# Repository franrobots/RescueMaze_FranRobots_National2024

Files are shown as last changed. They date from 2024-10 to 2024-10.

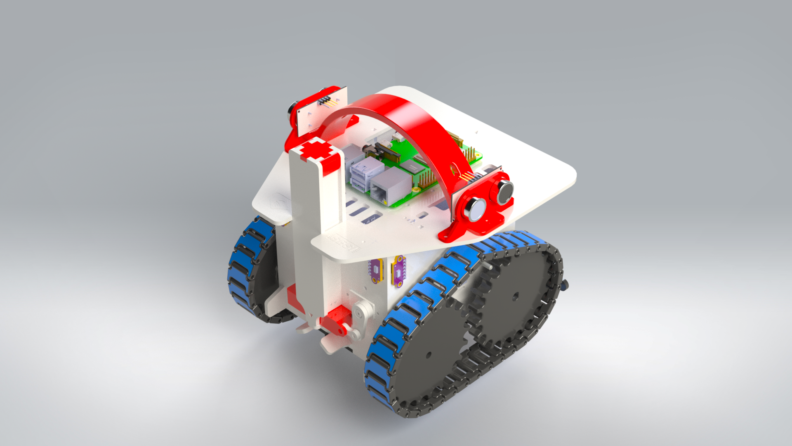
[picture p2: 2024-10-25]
Mechanics/MAZE ROBOT 2024/Extras/Render/Renders Robô/Projeto sem título.png

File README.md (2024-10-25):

# RescueMaze_FranRobots_National2024
🌎 Ready to face the exciting challenges of the Rescue Maze competition at RoboCup Junior! <br>

This repository is dedicated to organizing and centralizing documents, pictures, and files related to the 2024 Rescue Maze competition from RoboCup Junior, in [Goiania, BR](https://pt.wikipedia.org/wiki/Goi%C3%A2nia).

**Team Members:**
* [Arthur Mendes](https://www.instagram.com/arthurmlopezzz/) <br>
* [João Ribeiro](https://www.instagram.com/jaotavin/) <br>
* [Fernanda Lima](https://www.instagram.com/ferdilima_/) <br>
* [Guilherme Canteiro](https://www.instagram.com/guilhermebcanteiro/) <br>

<p align="center">
TeamMembers
<p align="center">  <strong> Team Members </strong> </p>

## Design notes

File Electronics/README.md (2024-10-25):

# Electronics ⚡

📜 This folder is intended for the [team's](https://www.instagram.com/fran_robots) robot electronic development. <br>

Here you can find the schematics, PCB layouts, and physical circuits of the project! [EasyEDA](https://easyeda.com/) is used to make the schematics and PCB layouts. <br> 
<br>
**Authors:**
* [Arthur Mendes](https://www.instagram.com/arthurmlopezzz/)
* [Guilherme Canteiro](https://www.instagram.com/guilhermebcanteiro/) <br>
<br>

> 💡 The electronics involve developing a robot that perceives its environment, makes decisions based on that perception, and executes actions necessary to **effectively** complete the competition tasks. <br>
> <br>
📟 Each electrical component plays a **specific** role in this process, working together to achieve **success** in the competition.

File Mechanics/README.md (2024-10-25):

# Mechanics
📜 This folder is designed to organize all robot mechanics-related content for the [team](https://github.com/franrobots), competing in the Rescue Maze category at RoboCup Junior. <br>

It contains essential documents, photos, and CAD ([SolidWorks](https://www.solidworks.com/)) project files. <br>
<br>

**Authors:**
* [Arthur Mendes](https://www.instagram.com/arthurmlopezzz/) <br>
* [Fernanda Lima](https://www.instagram.com/ferdilima_/) <br>
* [Guilherme Canteiro](https://www.instagram.com/guilhermebcanteiro/) <br>
<br>

> ⚙️ Mechanical development involves creating a **robust** structure, an **efficient** locomotion system, a **reliable** firing mechanism, and integrating precise electronic sensors to build an **effective** robot for competition.
<br>
<p align="center">
3D Assembly of the robot
<p align="center">  <strong> 3D Assembly of the Robot </strong> </p>

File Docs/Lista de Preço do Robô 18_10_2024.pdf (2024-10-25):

10/18/2024 | 1

### Lista de Preço do Robô - Fran Robots RCJ Rescue Maze

Item | Preço | Unidades por Pacote | Pacotes | Unidades Usadas | Total | Referência
LDR (Resistor Dependente de Luz) 5mm | R$14.32 | 100 unidades | 1 | 3 | R$14.32 | Link (https://pt.aliexpress.com/item/1005003401017855.html)
Resistor 1/4W 10K Ohm | R$8.22 | 100 unidades | 1 | 20 | R$8.22 | Link (https://pt.aliexpress.com/item/1005002369580841.html)
Resistor 1/4W 110 Ohm | R$8.22 | 100 unidades | 1 | 1 | R$8.22 | Link (https://pt.aliexpress.com/item/1005002369580841.html)
Resistor 1/4W 10K Ohm | R$8.22 | 100 unidades | 1 | 20 | R$8.22 | Link (https://pt.aliexpress.com/item/1005002369580841.html)
Resistor 1/4W 110 Ohm | R$8.22 | 100 unidades | 1 | 1 | R$8.22 | Link (https://pt.aliexpress.com/item/1005002369580841.html)
Capacitor 1uF 50V | R$14.91 | 50 unidades | 1 | 1 | R$14.91 | Link (https://pt.aliexpress.com/item/1005005248329912.html)
LED Branco Alto-brilho de 5mm | R$5.79 | 100 unidades | 1 | 3 | R$5.79 | Link (https://pt.aliexpress.com/item/32918676633.html)
CTK C9L3 Sensor Infravermelho Refletivo | R$7.00 | 1 unidade | 3 | 3 | R$21.00 | Link (https://www.acheicomponentes.com.br/chaves/chave-otica-infravermelha-refletiva-compacta-ctk-c9l3-ctk)
Motor DC de 50RPM com caixa de redução - MJ TEK8 12V | R$138.00 | 1 unidade | 2 | 2 | R$276.00 | Link (https://produto.mercadolivre.com.br/MLB-925938177)
Driver de Motor Dupla Ponte H L298N HS | R$19.90 | 1 unidade | 1 | 1 | R$19.90 | Link (https://www.eletrogate.com/ponte-h-dupla-l298n?gad_source=1)
Display de Bateria MH-DL18S | R$18.90 | 1 unidade | 1 | 1 | R$18.90 | Link (https://produto.mercadolivre.com.br/MLB-1159926996)
Bateria Lipo Leão 11.1v 3s 2.2ah 30c/60c | R$299.00 | 1 unidade | 1 | 1 | R$299.00 | Link (https://produto.mercadolivre.com.br/MLB-1697260577-bateria-lipo-111v-3s-2200mah-30c60c-xt60-_JM)
Conector Fêmea de Bateria XT60 | R$6.56 | 1 unidade | 1 | 1 | R$6.56 | Link (https://pt.aliexpress.com/item/1005003677606547.html)
Regulador Step Down DC-DC Mini 360 3A | R$7.22 | 1 unidade | 2 | 2 | R$14.44 | Link (https://es.aliexpress.com/item/1005006243045808.html)
Regulador Step Up DC-DC MT3608 2A | R$11.99 | 1 unidade | 1 | 1 | R$11.99 | Link (https://produto.mercadolivre.com.br/MLB-1840280546-modulo-regulador-dc-step-up-mt3608-conversor-pic-_JM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)
Placa Ilhada de Fenolite 10x10cm | R$12.90 | 1 unidade | 1 | 1 | R$12.90 | Link (https://www.robocore.net/placa-circuito/pcb-ilhada-10x10cm)
ESP32-WROOM-32 30 Pinos | R$4.99 | 1 unidade | 1 | 1 | R$4.99 | Link (https://es.aliexpress.com/item/1005006246777139.html)
Multiplexador I2C 8 Canais TCA9548A | R$8.53 | 1 unidade | 1 | 1 | R$8.53 | Link (https://es.aliexpress.com/item/1005006770076868.html)
GY-BNO055 9-Axis Abs. Orientation | R$44.20 | 1 unidade | 1 | 1 | R$44.20 | Link (https://es.aliexpress.com/item/1005006878899969.html)
VL53L0X Time-Of-Flight Laser Ranging Sensor | R$4.99 | 8 unidades | 1 | 8 | R$4.99 | Link (https://es.aliexpress.com/item/1005006719586781.html)
Módulo Sensor de Distância Ultrassônico HC-SR04 | R$11.90 | 1 unidade | 2 | 2 | R$23.80 | Link (https://www.eletrogate.com/modulo-sensor-de-distancia-ultrassonico-hc-sr04?gad_source=1)
Mini Rocker Switch KCD11-101 | R$1.60 | 10 unidades | 1 | 3 | R$1.60 | Link (https://www.eletrogate.com/mini-chave-gangorra-2-terminais?gad_source=1)
SG90 9G Micro Servo 180º | R$16.73 | 1 unidade | 1 | 1 | R$16.73 | Link (https://pt.aliexpress.com/item/1005006379480535.html)
Fita de LED RGB Individualmente Endereçável 5V | R$5.98 | 1 unidade | 1 | 1 | R$5.98 | Link (https://pt.aliexpress.com/item/4000636732242.html)
Raspberry PI 4 Modelo B 8GB | R$286.81 | 1 unidade | 1 | 1 | R$286.81 | Link (https://pt.aliexpress.com/item/1005005761716573.html)
WebCam Generica FullHD | R$16.27 | 1 unidade | 2 | 2 | R$32.54 | Link (https://pt.aliexpress.com/item/1005005831256349.html)
Cabo USB 1m | R$70.16 | 1 unidade | 1 | 1 | R$70.16 | Link (https://pt.aliexpress.com/item/1005005201739767.html)
Cabo USB A 2.0 1m | R$18.72 | 1 unidade | 2 | 2 | R$37.44 | Link (https://pt.aliexpress.com/item/1005006854476947.html)
Borne 2-Vias 5.08mm WJ128 | R$2.51 | 5 unidades | 2 | 9 | R$5.02 | Link (https://pt.aliexpress.com/item/1005006277429830.html)
Barra Pinada Macho 2.54mm 1x40 | R$19.74 | 10 unidades | 1 | 2 | R$19.74 | Link (https://pt.aliexpress.com/item/1005002577212594.html)
Barra Pinada Fêmea 2.54mm 1x40 | R$19.74 | 10 unidades | 1 | 3 | R$19.74 | Link (https://pt.aliexpress.com/item/1005002577212594.html)

10/18/2024
2
Jumper Fêmea 20cm | R$4.47 | 10 unidades | 1 | 2 | R$4.47 | Link (https://www.proesi.com.br/jumper-femea-x-femea-kit-com-10-unidades-12cm)
Cabo Flat Multi-colorido AWG26 | R$9.64 | 1 metro | 3 | 3 | R$28.92 | Link (https://www.eletrodex.net/cabos-e-fios/flat-cable/colorido/cabo-flat-colorido-awg26)
Alça Impressa em 3D | R$29.26 | 1 unidade | 1 | 1 | R$29.26
Caixa Tripla de LDR Impressa em 3D | R$16.58 | 1 unidade | 1 | 1 | R$16.58
Kit de Resgate Impresso em 3D | R$17.92 | 12 unidades | 1 | 12 | R$17.92
Suporte do Switch do Principal Impresso em 3D | R$16.04 | 1 unidade | 1 | 1 | R$16.04
Roda Motora Impressa em 3D | R$38.55 | 1 unidade | 2 | 2 | R$77.10
Roda Boba Impressa em 3D | R$37.71 | 1 unidade | 2 | 2 | R$75.42
Dentes da Esteira Impressos em 3D | R$53.21 | 20 unidades | 4 | 72 | R$212.84
Junção da Esteira Impressa em 3D | R$21.22 | 20 unidades | 4 | 72 | R$84.88
Pistão "Tapete" Impresso em 3D | R$17.39 | 1 unidade | 1 | 1 | R$17.39
Para-choque Tátil Meio Impresso em 3D | R$16.67 | 1 unidade | 1 | 1 | R$16.67
Para-choque Tátil Lateral Impresso em 3D | R$17.50 | 2 unidade | 1 | 2 | R$17.50
Tampa Disparador Impressa em 3D | R$16.40 | 1 unidade | 1 | 1 | R$16.40
Placa de Acrílico Transparente 3mm 60x40cm | R$67.00 | 1 unidade | 1 | 1 | R$67.00 | Link (https://produto.mercadolivre.com.br/MLB-3922190696-chapa-acrilico-cristal-60x40-cm-x-3-mm-artesanato-laser-_JM)
Cola de silicone 85g | R$12.94 | 1 unidade | 1 | 1 | R$12.94 | Link (https://www.casadosparafusosfranca.com.br/cola-fixa-tudo-ms-profissional-amazonas-bisnaga-85g-amazonas)
Borracha De Silicone Azul Alta Flexibilidade para Moldes | R$35.90 | 515 gramas | 1 | 200g | R$35.90 | Link (https://www.redelease.com.br/catalog/product/view/id/8530/s/borracha-de-silicone-azul-alta-flexibilidade-para-moldes-com-catalisador-515-g/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)
Parafuso Fenda M2.5 16mm | R$0.57 | 1 unidade | 14 | 14 | R$7.98 | Link (https://www.casadoresistor.com.br/parafuso-m2,5x16-cabeca-cilindrica-fenda-p7099)
Porca M2.5 | R$0.11 | 1 unidade | 26 | 26 | R$2.86 | Link (https://www.casadoresistor.com.br/porca-sextavada-m2,5-p7156)
Arruela M2.5 | R$0.14 | 1 unidade | 4 | 4 | R$0.56 | Link (https://www.megalojista.com.br/fixadores/arruelas/arruela-lisa/arruela-lisa-m2-5-2-7-x-6-x-0-55-din-125a-inox-a2-unidade.html)
Parafuso Allen Inox M3 12mm | R$0.36 | 1 unidade | 30 | 30 | R$10.80 | Link (https://www.dallanese.com.br/8169/pf-allen-c-cabea-mm-ma-inox-304)
Parafuso Fenda de Cabeça Chata M3 30mm | R$0.30 | 1 unidade | 2 | 2 | R$0.60 | Link (https://www.parafusofacil.com.br/ProdutosDetalhes.php?Codigo=1099274)
Parafuso Fenda M3 20mm | R$0.21 | 1 unidade | 8 | 8 | R$1.68 | Link (https://www.parafusofacil.com.br/ProdutosDetalhes.php?Codigo=1099229)
Parafuso Fenda de Cabeça Chata M3- 6mm | R$0.13 | 1 unidade | 8 | 8 | R$1.04 | Link (https://www.parafusofacil.com.br/ProdutosDetalhes.php?Codigo=1099267)
Porca Inox M3 | R$0.12 | 1 unidades | 51 | 51 | R$6.12 | Link (https://www.parafusofacil.com.br/porcas/porca-sextavada/porca-sextavada-ma-3-0-50-chave-5-5-inox-304a2-classe-70-passivado)
Porca Nylon Baixa MA3 | R$0.31 | 1 unidade | 2 | 2 | R$0.62 | Link (https://www.parafusofacil.com.br/ProdutosDetalhes.php?Codigo=1245278)
Arruela M3 | R$3.20 | 10 unidades | 1 | 8 | R$3.20 | Link (https://loja.forsetisolucoes.com.br/arruela-lisa)
Parafuso Allen Inox de Rosca Completa M4 30mm | R$1.14 | 1 unidade | 2 | 2 | R$2.28 | Link (https://www.parafusofacil.com.br/ProdutosDetalhes.php?Codigo=1112392)
Porca Inox M4 | R$0.15 | 1 unidade | 6 | 6 | R$0.90 | Link (https://www.parafusofacil.com.br/porcas/porca-sextavada/porca-sextavada-ma-4-0-70-chave-7-inox-304a2-classe-70-passivado/)
Arruela M4 | R$2.40 | 10 unidades | 1 | 4 | R$2.40 | Link (https://loja.forsetisolucoes.com.br/arruela-lisa)

Total Geral
R$2,119.13

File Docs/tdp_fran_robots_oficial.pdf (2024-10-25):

# RoboCupJunior Brasil – Rescue Maze – TDP Fran Robots

1

° Arthur Mendes Lopes
SESI-SP
Franca, Brasil
arthur.mendes2801@gm
ail.com

2° Fernanda de Lima
Gonçalves
SESI-SP
Franca, Brasil
fernandalima99995788
@gmail.com

3

° Guilherme Baptista
Canteiro
SESI-SP
Franca, Brasil
guilhermebcanteiro@gm
ail.com

4° João Otávio Silva
Ribeiro
SESI-SP
Franca, Brasil
silvaribeirojoaootavio@
gmail.com

Resumo — Este artigo apresenta o desenvolvimento de nosso robô para a competição RoboCupJunior Rescue Maze, realizado ao longo de um ano e três meses. Para a navegação, tratamos o labirinto como uma grade de vértices e arestas (grafos), permitindo ao robô construir um mapa eficiente para localizar-se e encontrar rotas inteligentes. Optamos por priorizar tarefas no core (núcleo) 0 da ESP32, configurando-as com prioridade 1, o que resultou em um aumento significativo na velocidade de execução do programa. No hardware, além de um para-choque sensível equipado com botões que detectam paredes e obstáculos ao colidir, fazemos o uso de um sensor ultrassônico que valida a identificação de vítimas pela Raspberry Pi 4, garantindo que elas estejam em uma parede próxima. Isso previne os problemas anteriores com a detecção de vítimas falsas em paredes distantes. Também desenvolvemos um sistema de disparo com mecanismo biela-manivela para lançar kits de resgate em ambas as direções (direita e esquerda), utilizando apenas um servo motor. Essas inovações visam aumentar a eficiência e a precisão nas missões de resgate, reduzindo o tempo de resposta e aumentando a capacidade de adaptação do robô ao ambiente.
Palavras-chave — Labirinto, RoboCupJunior-Brasil, Robótica-Educacional, Machine-Learning, K-Means.
I. VISÃO GERAL
É a segunda vez que estamos participando dessa competição, mas, nos inspiramos muito nos conhecimentos que adquirimos anteriormente na competição RoboCupJunior Rescue Line. Nesse ano, aprimoramos o design do nosso robô, buscando maior simplicidade e eficiência. A estrutura modular, com peças transparentes e 3D, facilita a manutenção e o diagnóstico de problemas. As esteiras, antes com borracha de câmara de ar, agora com silicone, garantem maior aderência em diferentes terrenos do labirinto.
Para a navegação autônoma, desenvolvemos um sistema em C++ [01] que representa o labirinto como um grafo [02], permitindo a construção de mapas e a busca de rotas otimizadas e inteligentes. Sensores detectam paredes, caminhos e vítimas nas paredes, auxiliando na localização e na tomada de decisões. A visão computacional, implementada em Python [03] com OpenCV [04], utiliza os 7 Momentos de Hu [05] e o algoritmo K-Means [06] para identificar e classificar vítimas com alta precisão, mesmo em condições de iluminação variável. Essa combinação de técnicas permite ao robô reconhecer padrões visuais complexos e adaptar-se às diferentes situações encontradas durante a competição.
Os aprimoramentos realizados no robô desde o ano passado resultaram em um desempenho consideravelmente melhor. Sua maior estabilidade e precisão na identificação de vítimas demonstram um avanço significativo em direção ao objetivo de criar um sistema de resgate autônomo mais eficiente.

II. PLANEJAMENTO GERAL DO PROJETO
O principal objetivo da nossa equipe nesta competição é aprimorar de forma significativa as capacidades de reconhecimento de imagem do nosso robô, buscando um desempenho otimizado. Para isso, definimos metas específicas
que | incluem | melhorar | a | precisão | do | sistema | de
reconhecimento e reduzir o tempo necessário para a conclusão das tarefas.
Nossas atividades estão registradas no Diário de Engenharia (Figura 1), desenvolvido no Canva [07], o que nos permitiu documentar nossas ações diárias com eficiência e manter uma organização clara. O diário também funciona como um planejador de metas a curto e longo prazo, além de incluir detalhes importantes de tarefas específicas. Registrar essas informações torna a execução dessas atividades mais prática no futuro, já que todos os procedimentos e soluções anteriores estão devidamente registrados.
O uso do Canva, que reúne todos os componentes do robô, também foi essencial durante o processo de montagem, proporcionando acesso simplificado e prático a informações críticas, como datasheets dos sensores.

FIGURA 1
PÁGINAS DO DIÁRIO DE ENGENHARIA DA FRAN ROBOTS, CAPA GERAL, CAPA DA ÁREA, PÁGINA ALEATÓRIA, RESPECTIVAMENTE.

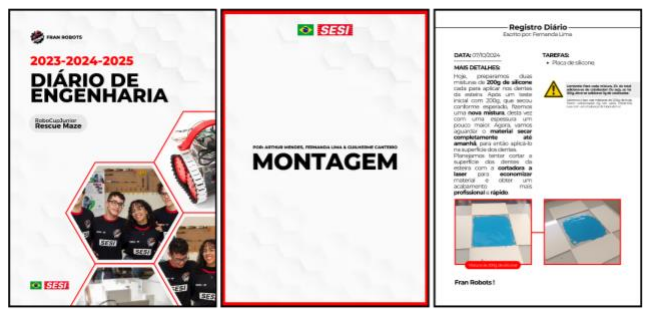
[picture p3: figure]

III. ESTRUTURA DO ROBÔ E ELETRÔNICA
Nosso robô foi projetado com uma arquitetura robusta e modular, permitindo adaptações rápidas e soluções eficazes durante a competição. O hardware principal é composto por uma série de componentes cuidadosamente selecionados e otimizados para garantir o máximo desempenho no labirinto.
A. Mecânica e Manufatura
1. Estrutura Principal
Projetado em CAD [08] (Figura 2a e 2b), o robô prioriza confiabilidade e estabilidade enquanto mantém um tamanho compacto, simplificando o desenvolvimento do software e da eletrônica. Ele possui fácil acesso por cima e por baixo, com poucos parafusos para manutenções rápidas. Porcas coladas com supercola em “junções T” (Figura 2c) evitam perdas e facilitam a montagem rápida. Os sensores e as câmeras são meticulosamente alinhados dentro das restrições físicas (tamanho e campo de visão), garantindo uma visão abrangente do labirinto.

FIGURA 2
(A) MODELO 3D DO ROBÔ; (B) ROBÔ REAL; (C) JUNÇÃO EM T.

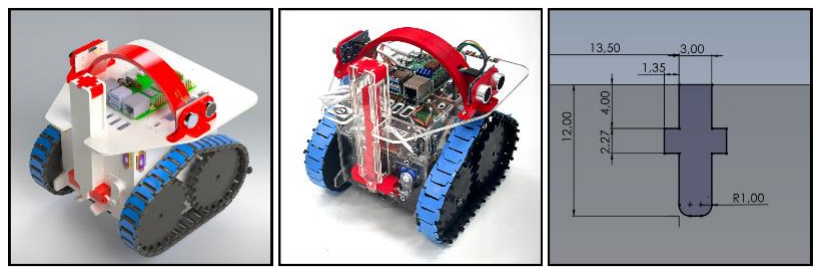
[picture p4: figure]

2. Rodas, Motores e Encoder As engrenagens, uma acionada por um motor e a outra livre (Figura 3a), movimentam as esteiras do robô. Um parafuso e uma porca são usados para fixação da “roda boba”. Os motores operam com tração nas rodas dianteiras, priorizando um melhor desempenho ao subir rampas, ao mesmo tempo que protegem o disparador de kits durante as descidas. Um encoder
[09] é colocado no lado direito com um ímã, dentro da roda livre (Figura 3b), Ele lê as rotações e as conta para validação dos ladrilhos e movimentos mais rápidos do robô

FIGURA 3
(A) RODA LIVRE (ESQUERDA) E RODA MOTORA (DIREITA); (B) RODA LIVRE E ÍMÃ DO ENCODER.

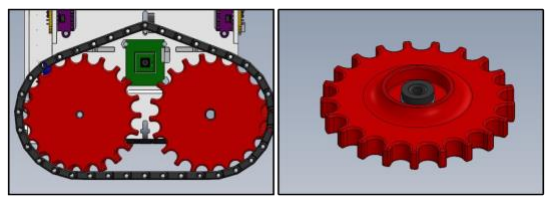
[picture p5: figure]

3. Esteiras Modulares
As esteiras do nosso robô foram baseadas em nossa estratégia anterior na Olímpiada Brasileira de Robótica [10]. Elas garantem maior estabilidade geral, especialmente ao subir escadas (Figura 4a), superar redutores de velocidade e navegar por detritos espalhados pela arena. A parte superior garante que as rodas não batam nas paredes do labirinto e as escalem, ajudando no alinhamento. Nossa esteira é modular. De maneira similar à elos de uma corrente, utilizar dentes impressos em filamento ABS e conectá-los por pinos (Figuras 4b, 4c) garante uma manutenção rápida e eficaz. A tensão da esteira pode ser facilmente ajustada por meio de um abrelongo na parte superior da peça, ele também serve de guia à esteira para que ela fique fora da visão da câmera. O tensionamento adequado se revelou crucial, pois afetou diretamente a movimentação prevista do robô. Para melhorar a aderência, adicionamos uma camada de silicone na superfície dos dentes (Figura 4d).

FIGURA 4
(A) ESTEIRAS DO ROBÔ SE MOLDANDO NA RAMPA; (B) DENTE DA ESTEIRA; (C) PINO DA ESTEIRA; (D) ESTEIRA COM SILICONE NO TOPO.

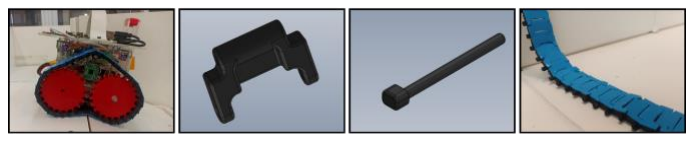
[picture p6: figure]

4. Para-choque táctil
O que anteriormente eram duas peças frontais passivas se tornou um para-choque com micro-switchs (Figura 5). Além da função anterior de prevenir um possível tombo frontal devido ao peso dos motores, agora ele também é capaz de, junto ao teto, ajudar nos alinhamentos e identificar obstáculos em ambas as extremidades do mesmo.

FIGURA 5
PARA-CHOQUE TÁTIL

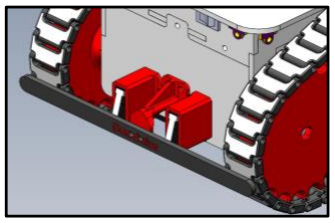
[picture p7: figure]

5. Módulos
Sensores de distância (Figura 6a), câmeras (Figura 6b), a placa de refletância, a parte superior, inferior e frontal inferior são modulares para permitir uma remoção independente e fácil do chassi. A fixação delas com parafusos e porcas embutidas foi aprendida através de experiências em competições passadas, pois facilita a manutenção e o diagnóstico.

FIGURA 6
(A) SENSORES DE DISTÂNCIA MODULARES; (B) ENCAIXE DA CÂMERA MODULAR.

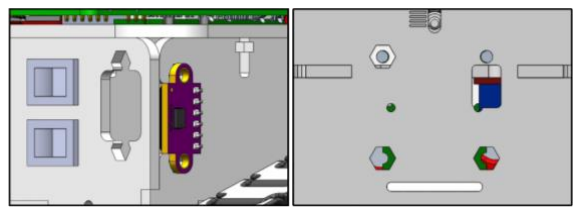
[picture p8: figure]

6. Mecanismo de Liberação dos Kits de Resgate
Melhoramos o mecanismo de disparo de kits de resgate do nosso robô, passando de um design unidirecional para um bidirecional, aumentando a precisão e eficiência. O novo mecanismo de biela-manivela (inspirado em uma ideia antiga de disparo por mola), é acionado por um servo motor que desliza, por meio de um êmbolo, suavemente os kits para ambos os lados sem que haja a necessidade de curvas do robô (Figura 7). Sua posição na traseira do robô evita que as esteiras atropelem os kits. Paredes laterais de limite que os impedem de baterem nas irregularidades da roda e terem seu escape alterado e abre-longos na manivela e biela do mecanismo que diminuem que travamentos ocasionais são as mais novas adições. Muitas versões foram criadas e registradas para garantir confiabilidade e precisão, prevenindo que os kits travem ou fiquem fora da área pontuável. Alguns registros estão na seção de mecânica do nosso GitHub [11].

FIGURA 7
SEQUÊNCIA DE OPERAÇÃO DO MECANISMO DE BIELA MANIVELA.

### 7. Materiais

- Placas de acrílico: O acrílico transparente proporciona visibilidade dos circuitos internos, auxiliando em diagnósticos, enquanto o acrílico preto, na parte inferior da tampa do chassi, previne a interferência nos sensores de cor da placa de refletância causada pela iluminação interna.
- Filamento ABS: O filamento de ABS possui baixa tolerância durante a impressão, durabilidade e resistência. Suas propriedades bem conhecidas facilitaram a confecção 3D e a simulação com CAE [12].
B. Design Eletrônico e Manufatura
- I2C: O sensor de distância infravermelho VL53L0X utiliza I2C [13] para conectividade com múltiplos sensores, detectando paredes e obstáculos. Um multiplexador de oito canais PCA9548A consolida os sensores em um único endereço, prevenindo interferências. Além disso, via I2C, o sensor giroscópio 9-DOF de orientação absoluta GY-BNO055 [14] rastreia a inclinação com precisão, protegido com papel alumínio aterrado para mitigar a interferência eletromagnética, funcionando como uma gaiola de Faraday [15].
- Câmeras: Duas webcams desmontadas nas laterais se conectam a uma Raspberry Pi 4 [16] via USB para identificação de vítimas. As webcams são genéricas e de baixo custo, conectadas com cabos USB, isso permite uma fácil substituição.
- Placa de refletância: Uma placa de circuito removível (Figura 8a) feita em placa ilhada, é posicionada no nível mais baixo do robô, agora, internamente. Ela contém um sensor emissor e receptor de infravermelho (C9L3), LEDs brancos de alta luminosidade de 5mm e LDRs com filtros de gelatina para cores vermelha, verde e azul. O sensor infravermelho detecta rapidamente a luminosidade da superfície e os filtros de gelatina atuam como barreiras ópticas RGB, simplificando a separação de cores no software, como mostrado no fluxograma (Figura 8b). Fisicamente, a luz consegue passar apenas pelo filtro de seu espectro luminoso, assim, quando deparado com uma superfície inteiramente azul a reflexão da luz branca dos LEDs adquiri essa característica e chega somente ao LDR coberto por esse filtro, gerando uma leitura de nível alto (circuito pulldown [17]), enquanto os outros se mantem com uma leitura de nível baixo. Com os três espectros RGB e uma leitura analógica estamos preparados para cores conhecidas e potenciais surpresas do desafio Super Teams e Técnico. Sua instalação interna agora permite o robô passar diretamente por cima de redutores paralelos às laterais do mesmo, solucionando problemáticas enfrentadas na fase mundial da última temporada.

FIGURA 8
(A) ROTEAMENTO DA PLACA DE REFLETÂNCIA E SUA FOTO; (B) FLUXOGRAMA DA LÓGICA DE IDENTIFICAÇÃO DE CORES.

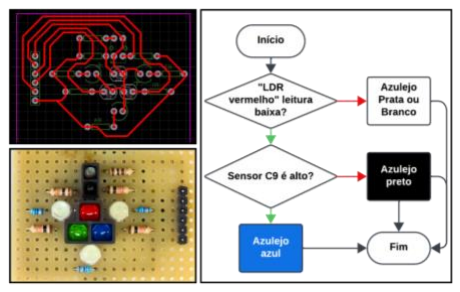
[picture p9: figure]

1. EasyEDA
Para criar esquemáticos, diagramas elétricos e rastreamento de circuitos, usamos o software de design eletrônico gratuito EasyEDA [18]. Ele preveniu erros de produção e economizou tempo e recursos. Conforme necessário, os circuitos foram modificados fisicamente e depois atualizados online, mantendo a documentação atualizada.
2. Controladores
- ESP32: O núcleo do robô, uma microcontroladora ESP32 [19], gerencia movimentos e decisões, processando dados dos sensores para distância, cor, orientação e classificação de vítimas. Foi escolhida por sua capacidade de multitarefa, velocidade, memória e tamanho compacto, quando comparado com um Arduino [20]. Um capacitor eletrolítico de baixa capacitância entre os pinos "EN" e "GND" permite a entrada automática no modo de programação do chip.
- Raspberry Pi 4: A Raspberry Pi 4 8GB [16] foi selecionada por seu alto processamento, velocidade, liberdade no código, dimensões compactas e confiabilidade. Ela envia todas as classificações das vítimas para a ESP32 via o protocolo UART [21], que executa a tarefa de resgate.
- Placa mãe: A placa central (Figura 9) agrupa os principais componentes, permitindo a substituição eficiente do "cérebro" do robô. A fiação interna e as trilhas de solda facilitam as conexões com bornes e conectores
posicionados | estrategicamente, | minimizando | os
comprimentos dos fios e garantindo substituições rápidas em caso de falhas ou defeitos.

FIGURA 9
FRENTE E VERSO DA PLACA MÃE

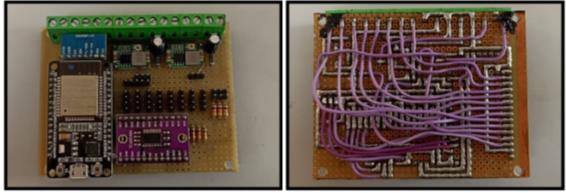
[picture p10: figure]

3. | Sistemas | e | Subsistemas | de
Alimentação
- Alimentação: Uma bateria LiPo de 12V 2.2Ah passa por dois reguladores de tensão Step-Down [22] Mini 360 e um Step-Up [23] Mt3608. Um dos reguladores Step-Down fornece 5V para um servomotor, uma fita de LEDs e a Raspberry Pi [16], e o outro fornece 3V3 para a ESP32 [19] e sensores gerais. Eles foram escolhidos devido ao seu tamanho compacto e capacidade de 3A. O regulador Step-Up Mt3608 eleva a tensão para 15V para o circuito de alimentação da Ponte-H [24], aumentando a velocidade e a eficiência do motor enquanto mantém sua potência. Cada regulador inclui capacitores de 220uF em suas saídas como filtros passa-baixa para reduzir os efeitos de chaveamento em alta frequência. Um display voltímetro (MH-DL18S) mostra os níveis da bateria, ajudando a manter a tensão do robô e prevenir seu uso excessivo durante os treinos.
- Motores e Drivers: Dois motores TEK8 12V 50 RPM, com redução de engrenagem e travas, são controlados por uma ponte H L298N para navegação eficiente e à prova de falhas. A redução de engrenagem do motor determina sua velocidade, enquanto suas travas físicas evitam rotações indesejadas durante o desligamento, aumentando a precisão especialmente em descidas. A maior tensão em relação aos níveis lógicos reduz o consumo de corrente, estendendo a vida útil dos componentes.

IV. SOFTWARE

O software, desenvolvido em C++ [01] e Python [03], apresenta algoritmos avançados de navegação, processamento de imagens em tempo real com OpenCV [04] e sistemas de controle precisos para operação eficiente e inteligente do robô. A navegação é programada em C++ e organizada em segmentos distintos. Para reconhecimento de vítimas, foram empregadas técnicas puras de processamento de imagem sem machine learning [25] pré-desenvolvido ou IA seguindo as etapas: Captura de Imagem, Segmentação e Classificação. Uma biblioteca de funções personalizada foi desenvolvida, contendo algoritmos frequentemente usados para simplificar o código final. Esta biblioteca inclui funções práticas para movimento, leitura de sensores e mapeamento de labirintos. Para sensores e atuadores específicos, utilizamos suas
respectivas | bibliotecas | públicas, | aproveitando | suas
implementações validadas para economizar tempo de desenvolvimento.
A. Navegação no Labirinto
O mapa é atualizado a cada novo azulejo visitado. Isso permite que o robô tome decisões ao escolher o próximo caminho, priorizando áreas não exploradas. Também focamos em movimentos precisos, enfatizando alinhamentos, cálculos de movimento e controles PD [26]. A lógica pode ser dividida em duas etapas, representadas pelos fluxogramas na Figura 10.

FIGURA 10
ANALISE DOS LADRILHOS DE COR; PROCESSO DE DECISÃO; TOMADA DE
| | ATITUDE.
B. Identificação de Imagem
A captura de imagem utiliza a biblioteca OpenCV [04] para processamento em tempo real das webcams de dois lados conectadas a uma Raspberry Pi 4 [16]. Primeiro, configuramos a resolução e a exposição das duas câmeras no Raspberry Pi e capturamos uma imagem de ambas, enviando-a para um filtro de segmentação de vítimas (baseado em thresholds adaptativos e de forma). Se alguma vítima é segmentada, a imagem resultante é enviada para a etapa de classificação. Para vítimas coloridas, consiste em filtros de faixa de três cores (verde, amarelo, vermelho) das imagens segmentadas convertidas para HSV [27], que são sujeitas a um limiar baseado no valor médio
dos | pixels. | Para | vítimas | alfanuméricas | (letras), | as
características da imagem são obtidas através dos 7 Momentos de Hu [05] e aplicadas à classificação estatística por meio de centroides obtidos por um algoritmo de agrupamento K-Means
[06] em um espaço tridimensional (aproximadamente 1500 imagens (500 amostras de cada letra H, S e U em diferentes ângulos e tamanhos) usadas para convergir os centroides de classificação do algoritmo K-Means). Os valores resultantes são enviados à microcontroladora ESP32 [19] via o barramento serial (protocolo UART [21]). As Figuras 11a e 11b representam esses métodos. Os resultados foram satisfatórios, com a maioria dos valores de confiança acima de 90%.

FIGURA 11
(A) FLUXOGRAMA DO ALGORITMO GERAL DE PROCESSAMENTO DE IMAGEM; ETAPAS DE SEGMENTAÇÃO E CLASSIFICAÇÃO DE VÍTIMAS.

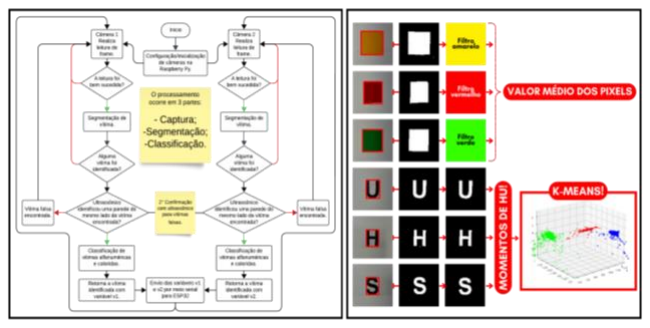
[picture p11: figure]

V. Inovações
A. Inovações Mecânicas e Elétricas:
- Silicone nos Dentes da Esteira: A camada de silicone nas esteiras do robô melhorou a tração em rampas e escadas do labirinto, se mostrando superior aos pedaços de câmara de ar anteriormente utilizados, pois é mais poroso e lida melhor com a sujeira.
- Formato Chanfrado do Último Andar: Os chanfros na extremidade traseira evitam que o robô colida com as paredes especialmente durante curvas sobre seu eixo. Solucionando muitos problemas que ocasionavam em desalinhamentos.
- Biela-manivela no Disparador de Kits de Resgate: Para dispensar os kits de forma bidirecional usando apenas um Servo motor, um mecanismo de biela-manivela aciona um êmbolo que direciona os kits para a direita ou esquerda. Abre-longos na estrutura mantêm o êmbolo sempre alinhado, enquanto um na manivela garante um movimento mais suave e evita travamentos, solucionando problemas das versões anteriores.
- Kit de Resgate Antiquique: O kit de resgate preenchido com bolinhas de estanho para solda solucionou nosso

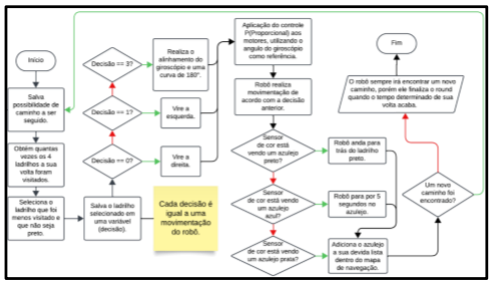
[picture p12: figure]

problema em que os mesmos quicavam para fora da área pontuável de 15 centímetros.
- Para-choque Tátil: O para-choque sensível ao toque manteve sua função de proteger as esteiras durante os alinhamentos e, além disso, detectam obstáculos no percurso.
- Sensores Modulares: Os sensores de distância e câmeras não são soldados diretamente. Em vez disso, são conectados |por barras pinadas, permitindo substituições rápidas e fáceis. A posição e o alinhamento são garantidos por parafusos e porcas previamente fixadas, o que facilita ainda mais a troca desses componentes.
- Placa de Refletância com Filtros de Cor: Para identificar os ladrilhos coloridos, utilizamos uma placa de refletância desenvolvida internamente, equipada com sensores LDR encapsulados e cobertos por filtros de gelatina luminosa nas três cores do espectro RGB. Esses filtros permitem a passagem apenas das cores correspondentes ao seu espectro. No código, quando um dos sensores registra um valor alto, os outros registram valores baixos, utilizando um circuito de pulldown.
- Placa Mãe com Componentes Modulares: Para identificar os ladrilhos coloridos, utilizamos uma placa de refletância desenvolvida internamente, equipada com sensores LDR encapsulados e cobertos por filtros de gelatina luminosa nas três cores do espectro RGB. Esses
filtros | permitem | a | passagem | apenas | das | cores
correspondentes ao seu espectro. No código, quando um dos sensores registra um valor alto, os outros registram valores baixos, utilizando um circuito de pulldown [17].
B. Inovações na Programação:
- K-Means: Utilizamos o conceito de K-Means para o processamento de imagem no momento de classificação das vítimas alfanuméricas. Utilizando de referência centroides gerados a partir de um banco de dados de cerca de 1500
imagens | com | vítimas | em | diferentes | ângulos | e
posicionamentos podemos agrupar e separar os frames coletados das vítimas ( H, S, U), classificando-as.
- BFS: É o algoritmo de busca no qual aplicamos ao mapeamento que nos retorna os ladrilhos identificados, e qual direção foi menos explorada, juntamente com a ordem de descoberta dos grafos.
- Biblioteca de Navegação no Labirinto: A biblioteca "Maze_FranRobots.h" foi desenvolvida por nós para auxiliar no controle de variáveis, rotas e mapeamento durante a navegação, além de implementar uma gama de funcionalidades essenciais.
- Gerenciamento de Conexões de Nó: A classe Node Connections gerencia as conexões entre diferentes nós no labirinto, armazenando até quatro conexões por nó e fornecendo métodos para defini-las e imprimi-las.
- Gerenciamento de Listas: A classe List é uma
implementação | personalizada | de | listas | dinâmicas,
semelhante ao que a biblioteca NumPy [28] faz em Python [03]. Ela permite alocação dinâmica de memória, redimensionamento, inserção, remoção e acesso a elementos, entre outras funcionalidades.
- Estrutura de Ponto: Define coordenadas bidimensionais dentro do labirinto, com métodos para inicialização e acesso às posições.
- Algoritmos | de | Navegação | e | Busca: | A | classe
"MazeRunner" é crucial para a navegação do robô. Ela mantém o estado atual do robô, posição, direção e nós visitados. Além disso, implementa algoritmos de busca, como BFS [29], para encontrar os caminhos mínimos entre nós e gerar instruções de movimento.
Esta biblioteca utiliza alocações dinâmicas de memória, que são essenciais para gerenciar grandes conjuntos de dados, como nós e conexões visitadas no labirinto (Figura 12). Ela oferece uma solução escalável para o controle do robô, com foco em navegação autônoma, utilizando listas inovadoras e algoritmos de busca robustos para maior eficiência.

FIGURA 12
À ESQUERDA ESTÁ O GRÁFICO DO LABIRINTO: VERDE ESCURO PARA OS VISITADOS, VERDE CLARO PARA OS CAMINHOS MAIS CURTOS. À DIREITA, ESTÁ

O FLUXOGRAMA DE NAVEGAÇÃO DO ROBÔ.

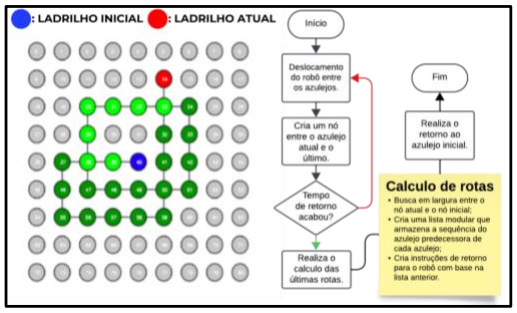
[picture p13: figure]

- Task Direto no Núcleo (Core) 0: Uma otimização de desempenho foi alcançada ao mover a execução do código no ESP32 [19] do “void loop” para uma tarefa de prioridade 1 no núcleo zero. Essa mudança interrompeu a
de-priorização | causada | pelo | sistema | operacional,
resultando em uma execução mais rápida.
- Botão de Interrupção Multitarefa: O segundo núcleo do nosso microcontrolador [19] lê um interruptor físico que congela o robô durante falhas de progresso, eliminando a necessidade de desligamentos e perda do mapa. Ele atualiza uma variável para ‘false’ quando ativado, solicitando que o código principal pule tarefas até que o interruptor seja desativado (Figura 13). Durante essa pausa, variáveis são ajustadas para refletir a posição atual do robô e a direção cardinal com base no último ponto de verificação.

FIGURA 13
INFOGRÁFICO DO PROCESSO DE INTERRUPÇÃO.

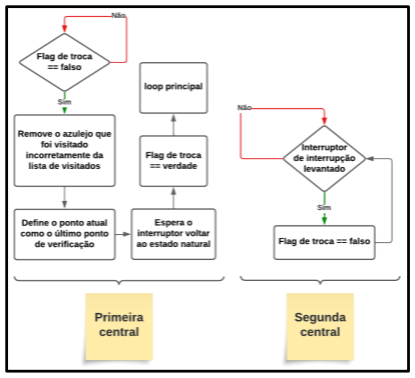
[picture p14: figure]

- Ultrassônico para Dupla Verificação de Vítima: Realizamos uma 2° verificação com o sensor ultrassônico no momento de identificação de vítimas, para evitar o reconhecimento de vítimas falsas.
No momento em que o sinal PWM chega para ESP32, analisamos se o sensor ultrassônico detecta uma parede a frente, caso sim ele dispara os kits, caso não ele identificou uma vítima falsa e não dispara os kits.

VI. AVALIAÇÃO DE PERFORMANCE

Na nossa inauguração na competição RoboCup Junior Rescue Maze, enfrentamos desafios relacionados ao tamanho do robô e às portas I2C [13] para os sensores de distância a laser. As dimensões do robô se mostraram problemáticas devido ao nosso treinamento em ladrilhos ligeiramente maiores, o que nos levou a reduzir o tamanho da Placa Mãe, do chassi e das rodas para melhor manobrabilidade. Além disso, enfrentamos uma sobrecarga de canais I2C, o que exigiu a integração de um multiplexador para consolidar os dados dos sensores em um único canal alternado. Identificar e resolver esses problemas foi essencial para nosso progresso e evolução
contínua | na | robótica.
Além disso, durante nossas sessões de treinamento, encontramos várias limitações com nosso robô. Contas detalhadas desses desafios estão meticulosamente registradas em nosso Diário de Engenharia [30], complementadas por vídeos dos problemas e suas soluções correspondentes, acessíveis através do nosso repositório GitHub [11] nas seções de mídia de cada área de trabalho respectiva. Uma tabela (Figura 14) mostra as principais mudanças feitas no disparador, montagem, modelos 3D, eletrônica, navegação no labirinto e reconhecimento de imagem desde que começamos a trabalhar na categoria (agosto de 2023), bem como ideias que tivemos, testamos, e que funcionaram ou não.

FIGURA 14
TABELA DE IDEIAS DURANTE AS TEMPORADAS DE 2023-2024 E 2024-2025

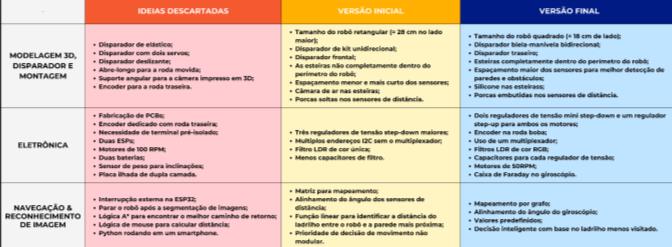
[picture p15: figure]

CONCLUSÃO
Com esta iniciativa, nosso objetivo é ter um impacto positivo na comunidade de robótica e avançar em nossa jornada profissional ao abraçar experiências e aprender com os erros. Identificamos desafios que permitiram que nosso projeto evoluísse de forma gradual e consistente. Nossos planos envolvem migrar o processamento de imagem para o Raspberry Pi [16] Zero para reduzir custos e consumo de energia. Além disso, estamos dedicados a expandir nossa proficiência em áreas críticas, como documentação, modelagem 3D, eletrônica, navegação e reconhecimento de imagem, para aprimorar
continuamente | nossos | projetos | futuros.
Em resumo, este trabalho representa uma evolução substancial desde nossa última participação na competição

RoboCup Junior em julho de 2024. Reconhecemos que a jornada científica é contínua e dinâmica. Avançando, continuaremos a iterar e implementar melhorias em todas as facetas do nosso projeto, enquanto colaboramos ativamente com outras equipes e educadores. A ciência nunca para, e nós também não.

REFERÊNCIAS
[1] C++ , o que é e por que você precisa aprender essa linguagem, https://www.dio.me/articles/c-o-que-e-e-por-quevoce-precisa-aprender-essa-linguagem, (https://www.dio.me/articles/c-o-que-e-e-por-que-voce-precisa-aprender-essa-linguagem) acessado por último em 17/10/2024.
[2] Teoria dos Grafos —Introdução, Definições, Matriz e Lista de Adjacência, https://medium.com/@anwarhermuche/teoriados-grafos-introdução-definições-matriz-e-lista-de-adjacência-2252d4800a44, (https://medium.com/@anwarhermuche/teoria-dos-grafos-introdu%C3%A7%C3%A3o-defini%C3%A7%C3%B5es-matriz-e-lista-de-adjac%C3%AAncia-2252d4800a44) acessado por último em 17/10/2024.
[3] O que é Python?, https://aws.amazon.com/pt/whatis/python, (https://aws.amazon.com/pt/what-is/python) acessado por último em 17/10/2024.
[4] | Uma | introdução | ao | OpenCV,
https://www.dio.me/articles/uma-introducao-ao-opencv, acessado por último em 17/10/2024.
[5] Shape Matching using Hu Moments (C++/Python), https://learnopencv.com/shape-matching-using-hu-momentsc-python, (https://learnopencv.com/shape-matching-using-hu-moments-c-python) acessado por último em 17/10/2024.
[6] Entendendo Clusters e K-Means, https://medium.com/cwisoftware/entendendo-clusters-e-k-means-56b79352b452, (https://medium.com/cwi-software/entendendo-clusters-e-k-means-56b79352b452) acessado por último em 17/10/2024.
[7] Sobre o Canva, https://www.canva.com/pt_br/about, acessado por último em 17/10/2024.
[8] | Software | CAD,
https://www.autodesk.com/br/solutions/cad-software, acessado por último em 17/10/2024.
[9] Encoder Incremental, https://blog.lri.com.br/encoderincremental-como-funciona-e-aplicacoes, (https://blog.lri.com.br/encoder-incremental-como-funciona-e-aplicacoes) acessado por último em 17/10/2024.
[10] Sobre a OBR, https://obr.robocup.org.br/sobre, acessado por último em 17/10/2024.
[11] Sobre o Git, https://docs.github.com/pt/get-started/usinggit/about-git, (https://docs.github.com/pt/get-started/using-git/about-git) acessado por último em 17/10/2024.
[12] Engenharia Assistida por Computador: o que é e como
funciona?, | https://www.esss.com/blog/engenharia-assistida-
por-computador-o-que-e-e-como-funciona, (https://www.esss.com/blog/engenharia-assistida-por-computador-o-que-e-e-como-funciona) | acessado | por
último em 17/10/2024.
[13] | Comunicação | I2C,
https://embarcados.com.br/comunicacao-i2c, | acessado | por
último em 17/10/2024.
[14] Adafruit 9-DOF Absolute Orientation IMU Fusion Breakout - BNO055, https://adafruit.com/product/2472, acessado por último em 17/10/2024.
[15] Gaiola de Faraday, o que é? Qual a sua aplicação?, https://www.mundodaeletrica.com.br/gaiola-de-faraday-o-
que-e-qual-a-sua-aplicacao, (https://www.mundodaeletrica.com.br/gaiola-de-faraday-o-que-e-qual-a-sua-aplicacao) | acessado | por | último | em
17/10/2024.
[16] O que é o Raspberry Pi, https://diolinux.com.br/tutoriais/oque-e-o-raspberry-pi.html, (https://diolinux.com.br/tutoriais/o-que-e-o-raspberry-pi.html) acessado por último em 17/10/2024.
[17] Entendendo os Resistores de Pull-Up e Pull-Down, https://blog.eletrogate.com/entendendo-os-resistores-de-pull-up-e-pull-down, (https://blog.eletrogate.com/entendendo-os-resistores-de-pull-up-e-pull-down) acessado por último em 17/10/2024.
[18] | About | EasyEDA, | https://easyeda.com/page/about,
acessado por último em 17/10/2024.
[19] | ESP32 | Pinout: | Detalhes | e | Conexões,

https://clubedomaker.com/esp32-pinout, acessado por último em 17/10/2024.
[20] | Arduíno: | o | que | é, | funções, | tipos | e | mais,
https://blog.kalatec.com.br/arduino-o-que-e, | acessado | por
último em 17/10/2024.
[21] | Compreender | UART, | https://www.rohde-
schwarz.com/br/produtos/teste-e-medicao/essentials-testequipment/digital-oscilloscopes/compreenderuart_254524.html, (https://www.rohde-schwarz.com/br/produtos/teste-e-medicao/essentials-test-equipment/digital-oscilloscopes/compreender-uart_254524.html) acessado por último em 17/10/2024.
[22] | Conversor | step | down,
https://www.wesen.com.br/conversor-step-down, acessado por último em 17/10/2024.
[23] Conversor step up, https://www.wesen.com.br/conversorstep-up, (https://www.wesen.com.br/conversor-step-up) acessado por último em 17/10/2024.
[24] | Ponte | H | – | O | que | é | e | como | funciona!,
https://www.manualdaeletronica.com.br/ponte-h-o-que-ecomo-funciona, (https://www.manualdaeletronica.com.br/ponte-h-o-que-e-como-funciona) acessado por último em 17/10/2024.
[25] | O | que | é | machine | learning | (ML)?,
https://cloud.google.com/learn/what-is-machine-learning?hl=pt-BR, (https://cloud.google.com/learn/what-is-machine-learning?hl=pt-BR) acessado por último em 17/10/2024.
[26] | O | Controlador | Proporcional-Derivativo | ( | PD),
https://www.ece.ufrgs.br/~jmgomes/pid/Apostila/apostila/nod e29.html, (https://www.ece.ufrgs.br/~jmgomes/pid/Apostila/apostila/node29.html) acessado por último em 17/10/2024.
[27] Teoria da cor aplicada aos sistemas digitais, https://sidigicor.blogspot.com/2011/02/modelo-hsv.html, acessado por último em 17/10/2024.
[28] Quem Somos, https://numpy.org/pt/about/, acessado por último em 17/10/2024.
[29] Métodos de Busca em Grafos — BFS & DFS, https://medium.com/@anwarhermuche/métodos-de-busca-em-
grafos-bfs-dfs-cf17761a0dd9, (https://medium.com/@anwarhermuche/m%C3%A9todos-de-busca-em-grafos-bfs-dfs-cf17761a0dd9) | acessado | por | último | em
17/10/2024.
[30] | Diário | de | Engenharia | Fran | Robots,
https://www.canva.com/design/DAGOUH4spuc/E9yPPvWn3bpYneac6GS2cQ/edit, (https://www.canva.com/design/DAGOUH4spuc/E9yPPvWn3bpYneac6GS2cQ/edit) acessado por último em 24/10/2024.

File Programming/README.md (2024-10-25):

# Programming

📜 This folder is intended for content related to the programming of the [team](https://www.instagram.com/fran_robots/) used in the Rescue Maze competition. <br>

Included here are the documents, photos, and the code used in the robot. <br>
<br>

**Authors:**
* [João Ribeiro](https://www.instagram.com/jaotavin/) <br>
<br>

> 📺 The programming utilizes C++ to control the robot's movement and Python to process images. <br> <br>
📷 Instead of using artificial intelligence, we constructed the **entire** architecture with the help of OpenCV, an **open-source** library that enables real-time image manipulation.

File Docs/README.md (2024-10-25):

# Docs 🗂️
📜This folder reunites all of the documentation regarding the project and the [team](https://www.instagram.com/fran_robots/). <br>

The engineering journal, TDP (Team Description Paper), poster, and many more are included!
<br>
<br>
**Authors:**
* [Fernanda Lima](https://www.instagram.com/ferdilima_/) <br>
<br>

> 📓 The documentation covers the **concise** recording of all aspects of the project, bringing them together to promote highly **effective** organization and presentation of all work carried out during the preceding period. <br> <br>
📊 It also contributes to the internal team management and schedules of the practices during the off-and-on season!

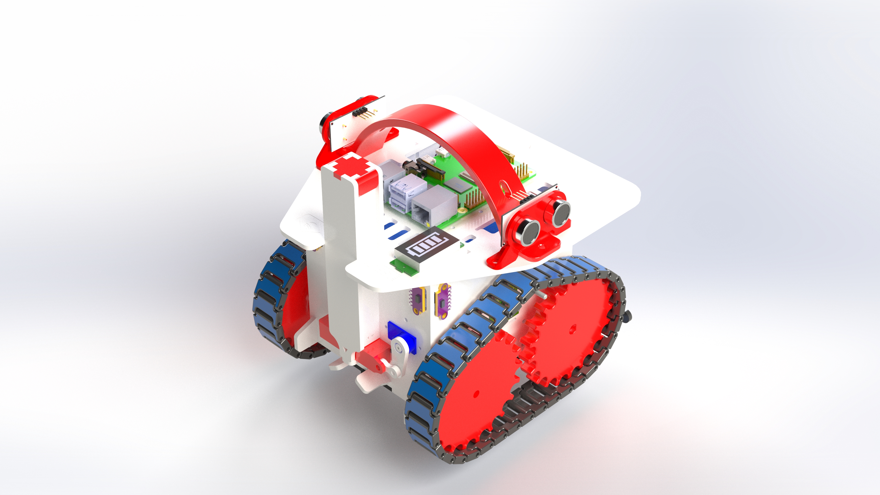
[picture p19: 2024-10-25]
Mechanics/MAZE ROBOT 2024/Extras/Render/Renders Robô/Projeto sem título (2).jpg

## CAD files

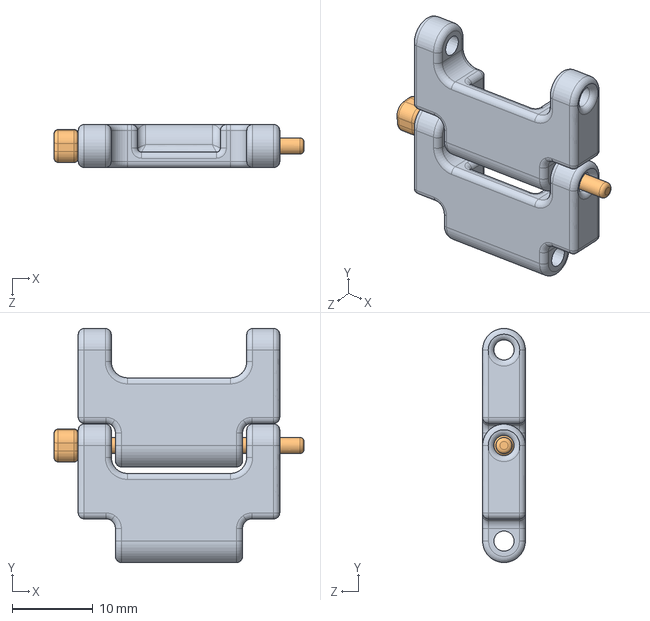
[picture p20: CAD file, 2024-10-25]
Mechanics/MAZE ROBOT 2024/Rodas e esteiras/Dentes Esteira/Montagem Dentes Esteira.SLDASM
31.0 x 29.0 x 5.32 mm
Dente Esteira - Engrenagem x 2
Eixo Junção Esteira

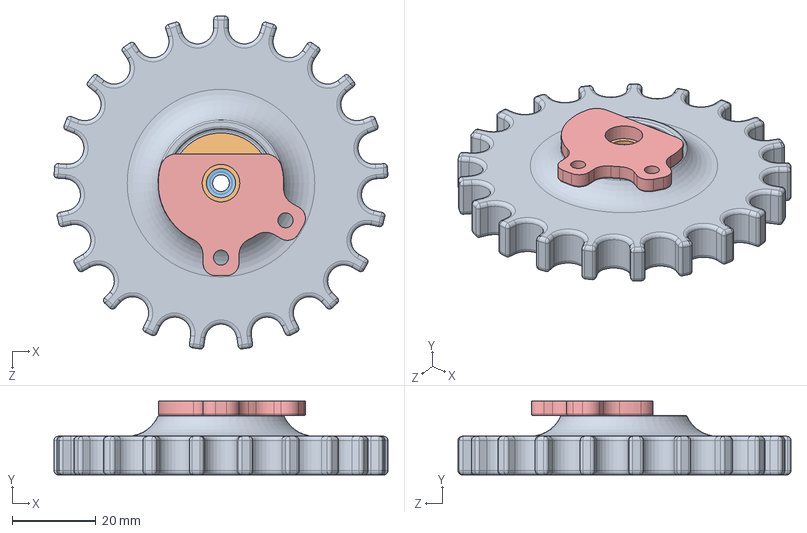
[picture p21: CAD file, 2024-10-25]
Mechanics/MAZE ROBOT 2024/Componentes/Encoder/Montagem Roda Mov. Encoder.SLDASM
79.8 x 17.6 x 79.6 mm
Engrenagem Mov. Red. Encoder - 11,92_7988
Imã Encoder Mod.
Arruela M4

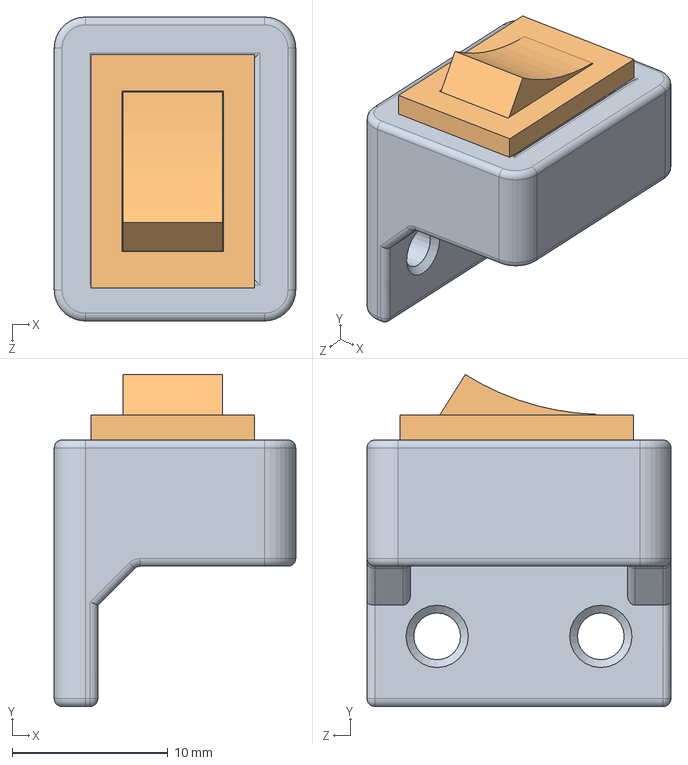
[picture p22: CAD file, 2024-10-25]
Mechanics/MAZE ROBOT 2024/Componentes/Switchs/3D/Montagem Suporte Main Switch.SLDASM
15.5 x 21.3 x 19.5 mm
Suporte Switch
tugas uts rocker switch

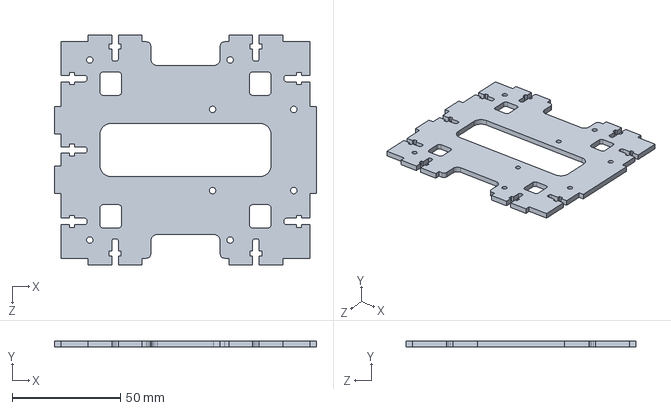
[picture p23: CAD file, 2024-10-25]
Mechanics/MAZE ROBOT 2024/Andar Principal - Maze.SLDPRT
121.0 x 3.00 x 106.0 mm

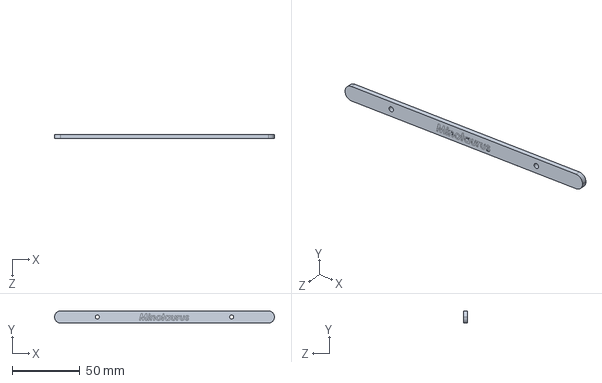
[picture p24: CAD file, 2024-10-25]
Mechanics/MAZE ROBOT 2024/Bumper/Chapas Bumber/Chapa Bumper - Minotaurus.SLDPRT
161.8 x 9.00 x 3.00 mm

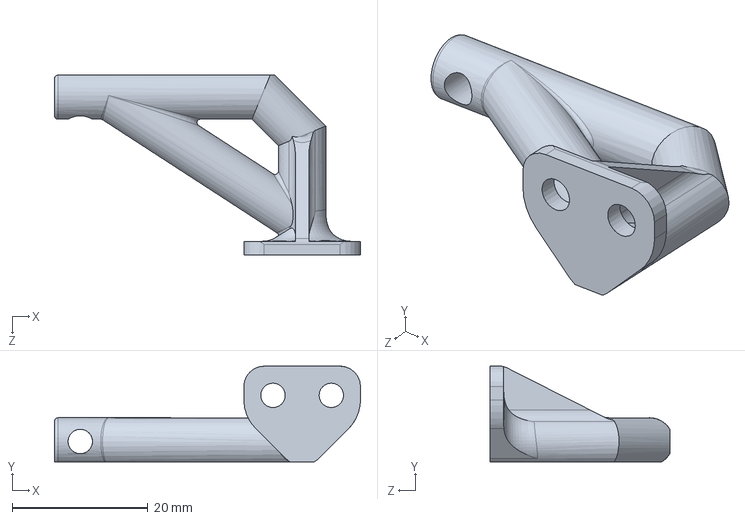
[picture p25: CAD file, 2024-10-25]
Mechanics/MAZE ROBOT 2024/Bumper/Peça Bumper Esquerda.SLDPRT
45.1 x 14.1 x 26.5 mm

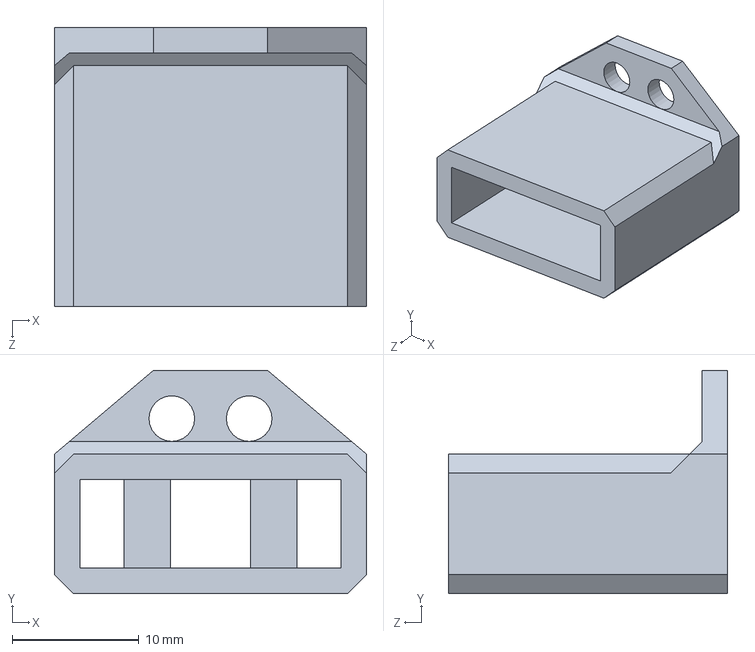
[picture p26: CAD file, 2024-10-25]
Mechanics/MAZE ROBOT 2024/Bumper/Switch Bumper/SwitchBumper Laterais.SLDPRT
24.6 x 17.6 x 22.0 mm

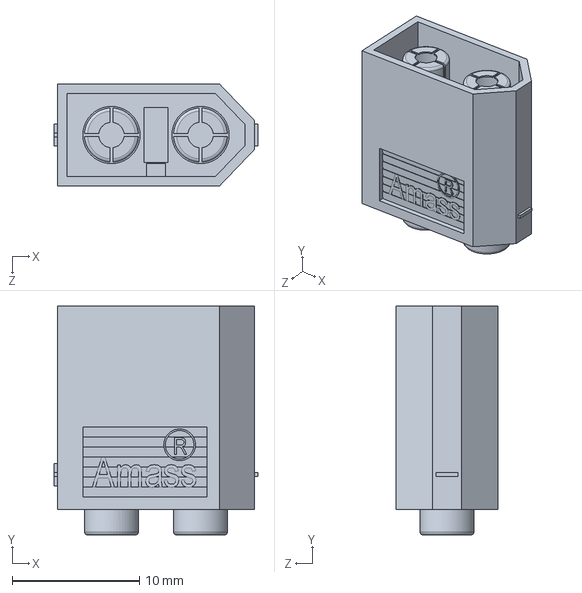
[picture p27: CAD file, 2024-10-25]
Mechanics/MAZE ROBOT 2024/Componentes/Bateria/PDB XT60 PLUG.SLDPRT
16.0 x 18.0 x 8.00 mm

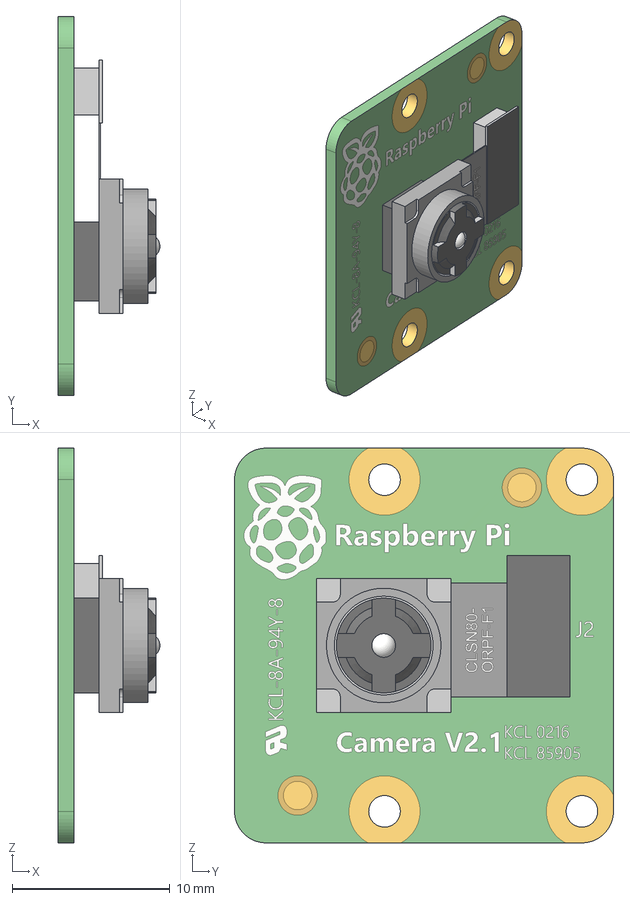
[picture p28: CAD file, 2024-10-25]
Mechanics/MAZE ROBOT 2024/Componentes/Câmera/Raspberry Cam.step
6.45 x 24.0 x 25.0 mm

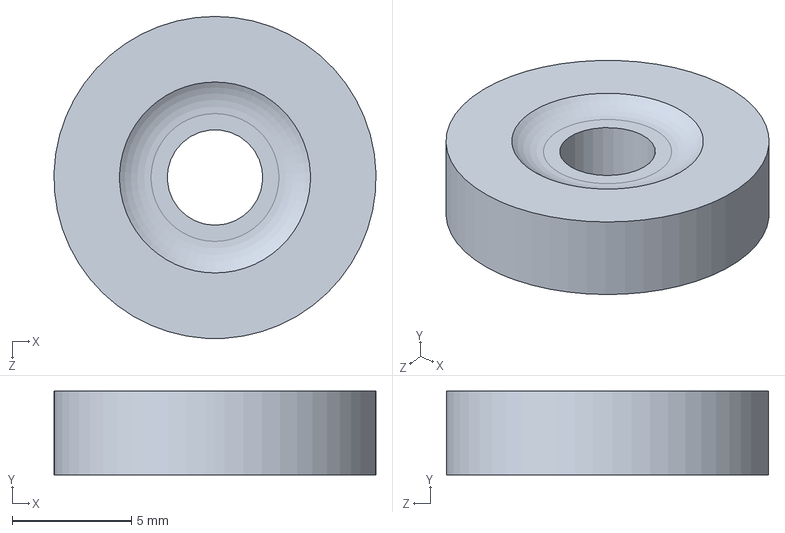
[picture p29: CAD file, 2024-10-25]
Mechanics/MAZE ROBOT 2024/Componentes/Encoder/Encoder Mod/Imã Encoder Mod..SLDPRT
13.5 x 3.50 x 13.5 mm

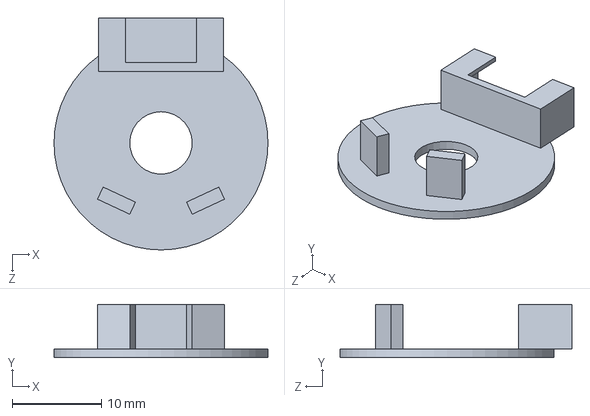
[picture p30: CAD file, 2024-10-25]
Mechanics/MAZE ROBOT 2024/Componentes/Encoder/Encoder Original/Encoder Motor.SLDPRT
24.0 x 6.00 x 26.0 mm

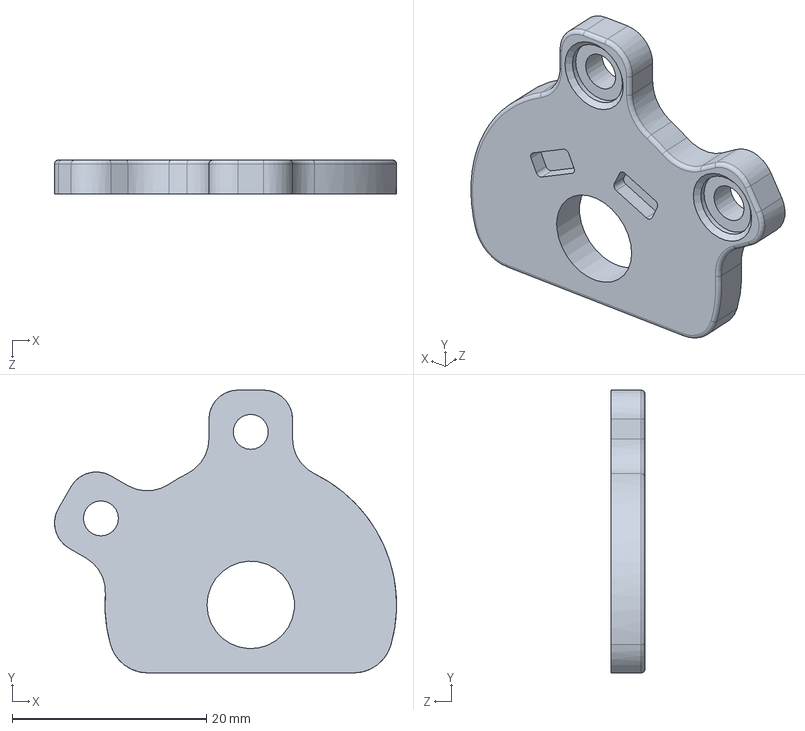
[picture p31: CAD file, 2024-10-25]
Mechanics/MAZE ROBOT 2024/Componentes/Encoder/Fixador Encoder Direita.SLDPRT
35.2 x 29.1 x 3.50 mm

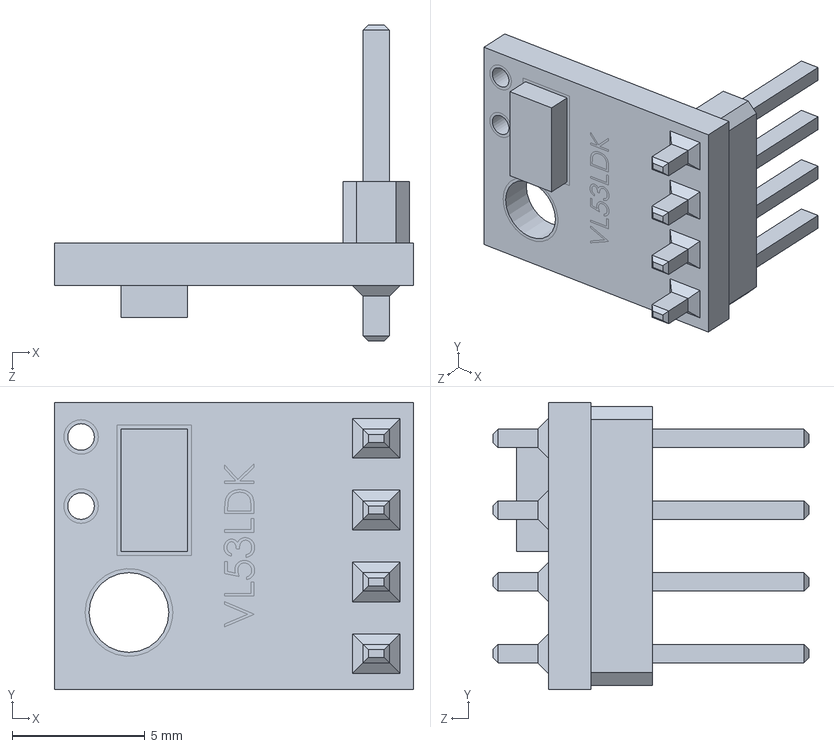
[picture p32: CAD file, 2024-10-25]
Mechanics/MAZE ROBOT 2024/Componentes/GY-VL53/GY-VL53LDK.SLDPRT
13.5 x 10.8 x 11.9 mm

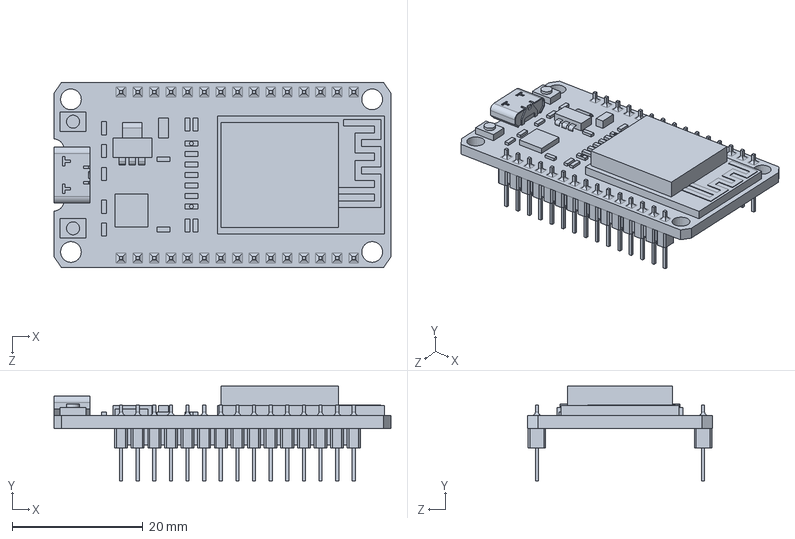
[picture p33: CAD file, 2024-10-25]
Mechanics/MAZE ROBOT 2024/Componentes/Micro-controladoras/ESP32.SLDPRT
51.5 x 14.5 x 28.3 mm

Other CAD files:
Mechanics/MAZE ROBOT 2024/Bumper/Rolling Bumper/Rolling Bumper Direita.SLDPRT
Mechanics/MAZE ROBOT 2024/Componentes/Micro-controladoras/RaspberryPi Zero/RaspberryPiZeroW.SLDPRT
Mechanics/MAZE ROBOT 2024/Componentes/Motor DC - MJ TEK8 - 12v 100 RPM.SLDPRT
Mechanics/MAZE ROBOT 2024/Componentes/Parafusos e Porcas/Arruelas/Arruela M3.SLDPRT
Mechanics/MAZE ROBOT 2024/Alça Robô Maze.SLDPRT
Mechanics/MAZE ROBOT 2024/Andar Base - Maze.SLDPRT
Mechanics/MAZE ROBOT 2024/Bumper/Chapas Bumber/Chapa Bumper - Daedalus.SLDPRT
Mechanics/MAZE ROBOT 2024/Bumper/Chapas Bumber/Chapa Bumper - Theseus.SLDPRT
Mechanics/MAZE ROBOT 2024/Bumper/Peça AntiCapotamento.SLDPRT
Mechanics/MAZE ROBOT 2024/Bumper/Peça Bumper Direita.SLDPRT
Mechanics/MAZE ROBOT 2024/Bumper/Switch Bumper/SwitchBumper Meio.SLDPRT
Mechanics/MAZE ROBOT 2024/Componentes/Bateria/Bateria 2200mAh 11.1V Lion Power.SLDPRT
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

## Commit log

2024-10-25 upload robot parts
    [Alça Robô Maze.SLDPRT, Andar Base - Maze.SLDPRT, Andar Principal - Maze.SLDPRT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]
2024-10-25 robot parts
    [Dente Esteira - Engrenagem.SLDPRT, Eixo Junção Esteira.SLDPRT, Engrenagem Motora Reduzida - Passo 11,92 7988.SLDPRT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]
